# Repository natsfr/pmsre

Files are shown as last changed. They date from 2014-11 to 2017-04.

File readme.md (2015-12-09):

#Powerful Motor System that Rocks Everything

##Presentation
PMSRE is a motor control system originally designed to drive a PCB CNC, a 3D printer and a microscope stage.
This project is based on a STM32F103 + 3x DRV8825 from TI and a Xilinx FPGA Spartan3A 50k or 200k. The main
point of using FPGA is too provide an easy way to extend the board with daughter board and to make real
line and curve machining in CNC.

##Hardware

  PCB is 4 Layers.

##Software

  OpenOCD scripts
  ---------------

  GDB  : openocd -f scripts/openocd/pmsre.cfg -c "gdb_port 4000"
  FLASH: openocd -f scripts/openocd/pmsre.cfg -c "program <elf binary> verify reset"

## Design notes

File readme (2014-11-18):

============================
== Powerfull Motor System ==
== Rocks Everything       ==
============================

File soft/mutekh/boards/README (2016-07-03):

=== OpenOCD ===

cd mutekh/
make BUILD=stm32-f103rg:shell CONF=~/pmsre/soft/mutekh/boards/config
openocd -f interface/ftdi/dp_busblaster.cfg -f target/stm32f1x.cfg -c init -c targets -c halt -c "flash write_image erase pmsre-stm32-f1.out" -c reset run -c shutdown

=== Segger ===

cd mutekh/
make BUILD=stm32-f103rg:shell:binary CONF=~/pmsre/soft/mutekh/boards/config TARGET_EXT=bin
( echo 'device STM32F103RG' ; echo 'loadbin pmsre-stm32-f1.bin 0' ; echo 'r' ; echo 'exit' ) | JLinkExe

==============

Flashing may fail when the mcu is idle, run the
follwing command in the mutekh shell in this case:

dev.timer.wait --timer-dev timer* --msec 10000 --busy-wait

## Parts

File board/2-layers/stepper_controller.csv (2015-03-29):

Reference | Value | Footprint | Datasheet
R201 | 0 | General_SMD:SM0603 | 594-MCT06030Z0000ZP5
R210 | 0 | General_SMD:SM0603 | 594-MCT06030Z0000ZP5
R207 | 22 | General_SMD:SM0603 | 660-RK73H1HTTC22R0F
R208 | 22 | General_SMD:SM0603 | 660-RK73H1HTTC22R0F
R204 | ? | General_SMD:SM0603
R205 | ? | General_SMD:SM0603
R113 | 0.1 | General_SMD:SM1206 | 66-LR1206LF-01-R100F
R114 | 0.1 | General_SMD:SM1206 | 66-LR1206LF-01-R100F
R115 | 0.1 | General_SMD:SM1206 | 66-LR1206LF-01-R100F
R116 | 0.1 | General_SMD:SM1206 | 66-LR1206LF-01-R100F
R117 | 0.1 | General_SMD:SM1206 | 70-LR1206LF-01-R100F
R118 | 0.1 | General_SMD:SM1206 | 70-LR1206LF-01-R100F
C104 | 0.1u | General_SMD:SM0603 | 77-VJ0603V104ZXACBC
C105 | 0.1u | General_SMD:SM0603 | 77-VJ0603V104ZXACBC
C106 | 0.1u | General_SMD:SM0603 | 77-VJ0603V104ZXACBC
C120 | 0.1u | General_SMD:SM0603 | 77-VJ0603V104ZXACBC
C307 | 0.1uF | General_SMD:SM0603 | 77-VJ0603V104ZXACBC
C101 | 0.47u | General_SMD:SM0603 | 77-VJ0603V474ZXJPBC
C102 | 0.47u | General_SMD:SM0603 | 77-VJ0603V474ZXJPBC
C103 | 0.47u | General_SMD:SM0603 | 77-VJ0603V474ZXJPBC
R206 | 1.5k | General_SMD:SM0603 | 71-CRCW0603-1.5K-E3
R304 | 100k | General_SMD:SM0603 | 71-CRCW0603-100K-E3
C122 | 100n | General_SMD:SM0603 | 77-VJ0603V104ZXACBC
C123 | 100n | General_SMD:SM0603 | 77-VJ0603V104ZXACBC
C124 | 100n | General_SMD:SM0603 | 77-VJ0603V104ZXACBC
C403 | 100n | General_SMD:SM0603 | 77-VJ0603V104ZXACBC
C404 | 100n | General_SMD:SM0603 | 77-VJ0603V104ZXACBC
C405 | 100n | General_SMD:SM0603 | 77-VJ0603V104ZXACBC
C409 | 100n | General_SMD:SM0603 | 77-VJ0603V104ZXACBC
C411 | 100n | General_SMD:SM0603 | 77-VJ0603V104ZXACBC
C413 | 100n | General_SMD:SM0603 | 77-VJ0603V104ZXACBC
C415 | 100n | General_SMD:SM0603 | 77-VJ0603V104ZXACBC
R202 | 10k | General_SMD:SM0603 | 71-CRCW0603-10K-E3
R209 | 10k | General_SMD:SM0603 | 71-CRCW0603-10K-E3
R301 | 10k | General_SMD:SM0603 | 71-CRCW0603-10K-E3
R307 | 10k | General_SMD:SM0603 | 71-CRCW0603-10K-E3
C107 | 10n | General_SMD:SM0603 | 77-VJ0603Y103KXAAC
C108 | 10n | General_SMD:SM0603 | 77-VJ0603Y103KXAAC
C109 | 10n | General_SMD:SM0603 | 77-VJ0603Y103KXAAC
C121 | 10n | General_SMD:SM0603 | 77-VJ0603Y103KXAAC
C406 | 10n | General_SMD:SM0603 | 77-VJ0603Y103KXAAC
C407 | 10n | General_SMD:SM0603 | 77-VJ0603Y103KXAAC
C308 | 10nF | General_SMD:SM0603 | 77-VJ0603Y103KXAAC
C311 | 10uF | General_SMD:SM0805 | 77-VJ0805G106KXQTBC
C313 | 10uF | General_SMD:SM0805 | 77-VJ0805G106KXQTBC
C314 | 10uF | General_SMD:SM0805 | 77-VJ0805G106KXQTBC
C315 | 10uF | General_SMD:SM0805 | 77-VJ0805G106KXQTBC
C304 | 10uF | General_SMD:SM1210 | 963-TMK325F106ZH-T
C305 | 10uF | General_SMD:SM1210 | 963-TMK325F106ZH-T
L302 | 10uH | General_SMD:IND_7x7x4.5 | 810-SLF755T100M2R5PF
P301 | 12V_Conn | Connectors_508mm:MOL_CONN_2_VH | #####################
R107 | 1M | General_SMD:SM0603 | 71-CRCW0603-1.0M-E3
R108 | 1M | General_SMD:SM0603 | 71-CRCW0603-1.0M-E3
R109 | 1M | General_SMD:SM0603 | 71-CRCW0603-1.0M-E3
C119 | 1u | General_SMD:SM0603 | 963-TMK107BJ105KA-T
C401 | 1u | General_SMD:SM0603 | 963-TMK107BJ105KA-T
C402 | 1u | General_SMD:SM0603 | 963-TMK107BJ105KA-T
C408 | 1u | General_SMD:SM0603 | 963-TMK107BJ105KA-T
C410 | 1u | General_SMD:SM0603 | 963-TMK107BJ105KA-T
C412 | 1u | General_SMD:SM0603 | 963-TMK107BJ105KA-T
C414 | 1u | General_SMD:SM0603 | 963-TMK107BJ105KA-T
L301 | 1u | General_SMD:SM1210L | 81-LQM32PN1R0MG0L
C201 | 1uF | General_SMD:SM0603 | 963-TMK107BJ105KA-T
C202 | 1uF | General_SMD:SM0603 | 963-TMK107BJ105KA-T
C203 | 1uF | General_SMD:SM0603 | 963-TMK107BJ105KA-T
C204 | 1uF | General_SMD:SM0603 | 963-TMK107BJ105KA-T
C205 | 1uF | General_SMD:SM0603 | 963-TMK107BJ105KA-T
C206 | 1uF | General_SMD:SM0603 | 963-TMK107BJ105KA-T
C207 | 1uF | General_SMD:SM0603 | 963-TMK107BJ105KA-T
C312 | 1uF | General_SMD:SM0805 | 77-VJ0805V105ZXJCBC
C309 | 1uF | General_SMD:SM1210 | 603-CC121KKX7R8BB105
R302 | 200k | General_SMD:SM0603 | 71-CRCW0603-200K-E3
R303 | 200k | General_SMD:SM0603 | 71-CRCW0603-200K-E3
R308 | 30.9k | General_SMD:SM0603 | 71-CRCW0603-30.9K-E3
R305 | 4.42k | General_SMD:SM0603 | 71-CRCW0603-4.42K-E3
C306 | 4.7nF | General_SMD:SM0603 | 963-TMK107B7474KA-TR
C110 | 4.7u | General_SMD:SM0805 | 570-08053D475K
C111 | 4.7u | General_SMD:SM0805 | 571-08053D475K
C112 | 4.7u | General_SMD:SM0805 | 572-08053D475K
C113 | 4.7u | General_SMD:SM0805 | 573-08053D475K
C114 | 4.7u | General_SMD:SM0805 | 574-08053D475K
C115 | 4.7u | General_SMD:SM0805 | 575-08053D475K
C116 | 4.7u | General_SMD:SM0805 | 576-08053D475K
C117 | 4.7u | General_SMD:SM0805 | 577-08053D475K
C118 | 4.7u | General_SMD:SM0805 | 578-08053D475K
C301 | 4.7u | General_SMD:SM0805 | 579-08053D475K
C302 | 4.7u | General_SMD:SM0805 | 580-08053D475K
C303 | 4.7u | General_SMD:SM0805 | 581-08053D475K
C310 | 4.7uF | General_SMD:SM1210 | 963-GMK325BJ475MN-T
R306 | 47k | General_SMD:SM0603 | 594-MCT06030C4702FP5
D202 | BUSY_ORANGE | General_SMD:LED-0805 | 755-SML-M13DTT86
P202 | CONN_2 | Connectors_254mm:pin_array_2x1 | #####################
P201 | CONN_2X2 | Connectors_254mm:pin_array_2x2 | #####################
P103 | CONN_4 | Connectors_508mm:MOL_CONN_4_VH | #####################
P105 | CONN_4 | Connectors_508mm:MOL_CONN_4_VH | #####################
P107 | CONN_4 | Connectors_508mm:MOL_CONN_4_VH | #####################
P108 | CONN_4X2 | Connectors_254mm:pin_array_4x2 | #####################
P106 | CONN_6X2 | Connectors_254mm:pin_array_6x2 | #####################
P104 | CONN_8X2 | Connectors_254mm:pin_array_8x2 | #####################
C208 | CSMALL | General_SMD:SM0603 | 81-GCM1885C2A160JA6D
C209 | CSMALL | General_SMD:SM0603 | 81-GCM1885C2A160JA6D
U101 | DRV8825 | SSOP:HTSSOP28_PowerPad | #####################
U102 | DRV8825 | SSOP:HTSSOP28_PowerPad | #####################
U103 | DRV8825 | SSOP:HTSSOP28_PowerPad | #####################
P101 | JTAG | Connectors_254mm:pin_array_6x1 | #####################
P102 | JTAG | Connectors_254mm:pin_array_6x1 | #####################
U104 | MAX5713/4/5-TSSOP14 | SSOP:SSOP14 | #####################
U301 | MP2128-SOT23 | General_SMD:SOT23-5 | #####################
U302 | MP2303_SOIC8E | SOIC:SO8_WITH_EP | #####################
R101 | NE | General_SMD:SM0603
R102 | NE | General_SMD:SM0603
R103 | NE | General_SMD:SM0603
R104 | NE | General_SMD:SM0603
R105 | NE | General_SMD:SM0603
R106 | NE | General_SMD:SM0603
R403 | NE | General_SMD:SM0603
D203 | POWER_GREEN | General_SMD:LED-0805 | 720-LGR971-KN-1
R401 | R | General_SMD:SM0603
R402 | R | General_SMD:SM0603
R404 | R | General_SMD:SM0603
U201 | STM32F103RG_LQFP64 | QFP:LQFP_64 | #####################
X201 | TXC_50X32_AB | Xtal_SMD:XTAL_5.0x3.2mm | #####################
J201 | USB_OTG | Connectors_USB:Molex_54819-0572 | 538-54819-0572
U401 | XC3S200A | QFP:TQFP_100 | #####################

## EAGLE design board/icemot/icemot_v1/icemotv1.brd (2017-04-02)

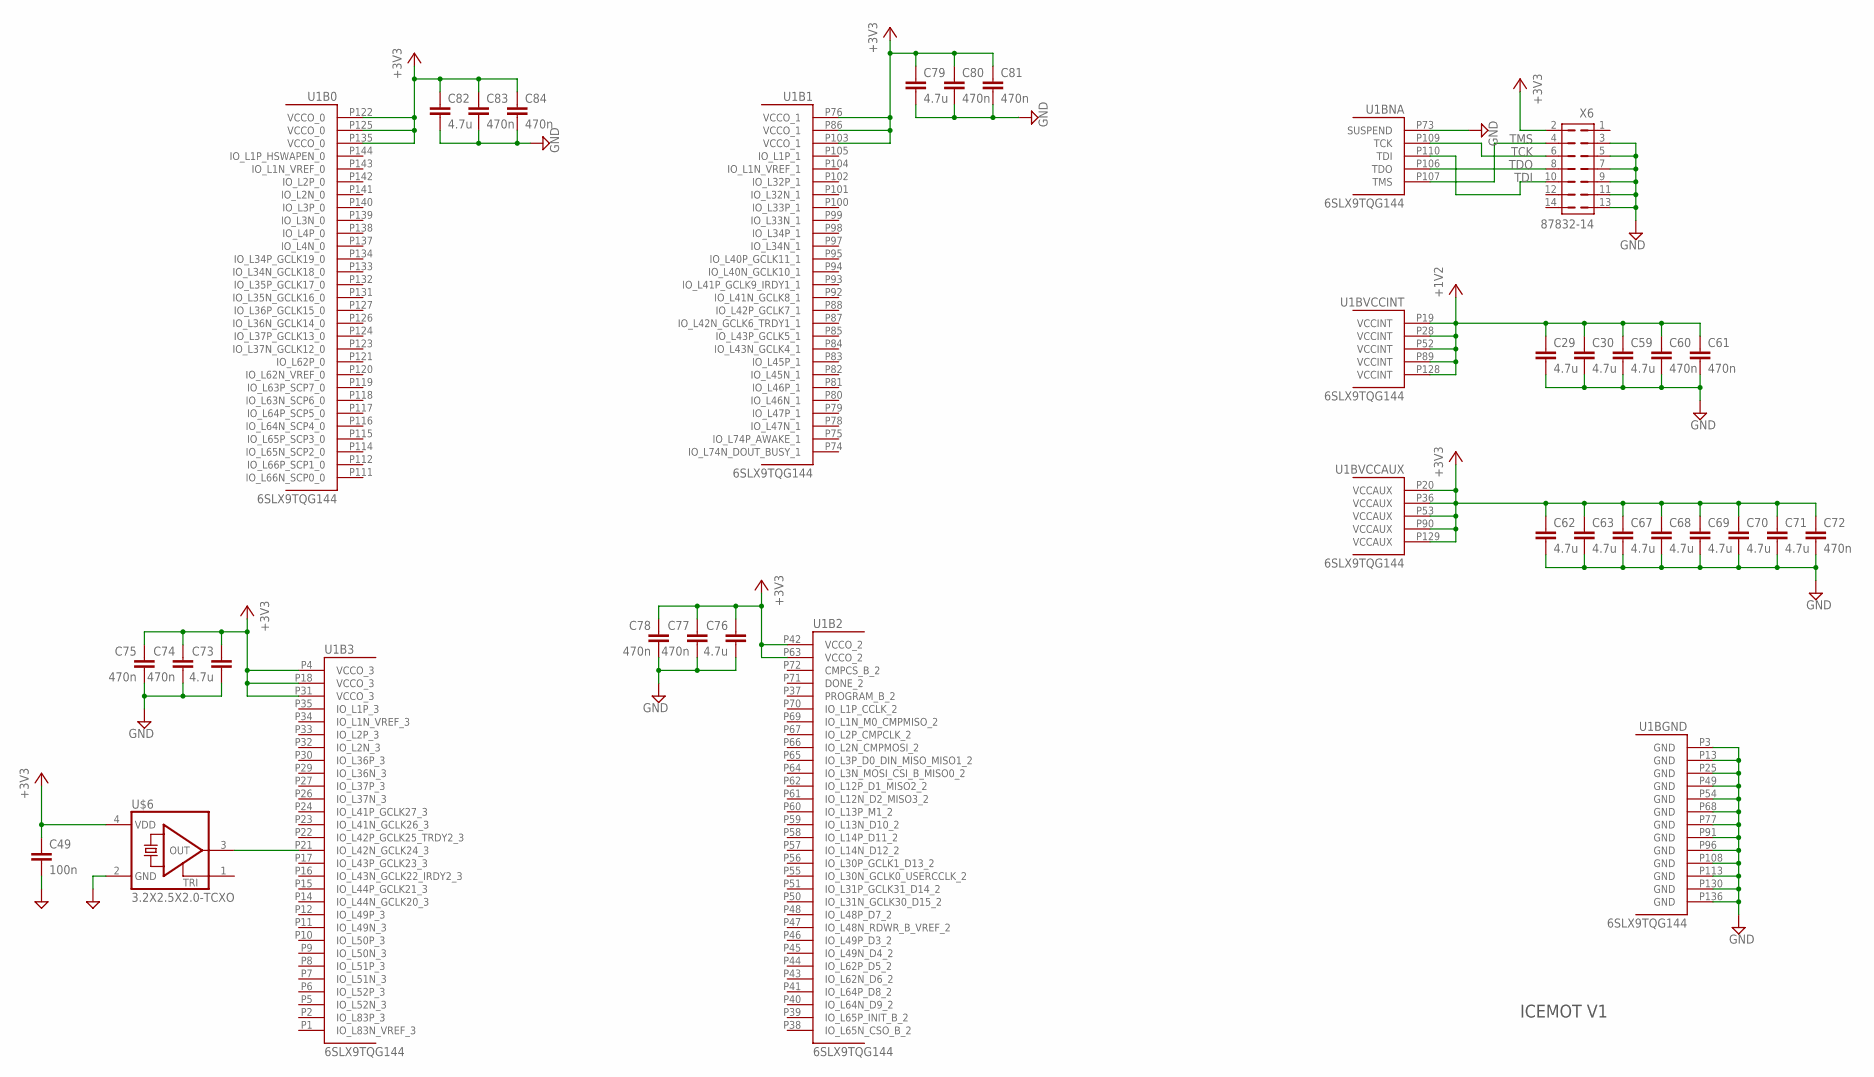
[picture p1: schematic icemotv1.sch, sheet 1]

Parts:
C29, C30, C59, C62, C63, C67, C68, C69, C70, C71, C73, C76, C79, C82: 4.7u; C0603
C49: 100n; R0603
C60, C61, C72, C74, C75, C77, C78, C80, C81, C83, C84: 470n; C0603
U1: 6SLX9TQG144; TQ144
U$6: 3.2X2.5X2.0-TCXO
X6: 87832-14

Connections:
+1V2: C29.1, C30.1, C59.1, C60.1, C61.1
+3V3: C49.1, C62.1, C63.1, C67.1, C68.1, C69.1, C70.1, C71.1, C72.1, C73.1, C74.1, C75.1, C76.1, C77.1, C78.1, C79.1, C80.1, C81.1, C82.1, C83.1, C84.1, U1.P20 (VCCAUX), U1.P36 (VCCAUX), U1.P53 (VCCAUX), U1.P90 (VCCAUX), U1.P129 (VCCAUX), U$6.4 (VDD), X6.2; also elsewhere on the board
GND: C29.2, C30.2, C49.2, C59.2, C60.2, C61.2, C62.2, C63.2, C67.2, C68.2, C69.2, C70.2, C71.2, C72.2, C73.2, C74.2, C75.2, C76.2, C77.2, C78.2, C79.2, C80.2, C81.2, C82.2, C83.2, C84.2, U1.P3 (GND), U1.P13 (GND), U1.P25 (GND), U1.P49 (GND), U1.P54 (GND), U1.P68 (GND), U1.P73 (SUSPEND), U1.P77 (GND), U1.P91 (GND), U1.P96 (GND), U1.P108 (GND), U1.P113 (GND), U1.P130 (GND), U1.P136 (GND), U$6.2 (GND), X6.3, X6.5, X6.7, X6.9, X6.11, X6.13; also elsewhere on the board
unnamed: U1.P21 (IO_L42N_GCLK24_3), U$6.3 (OUT)
TCK: U1.P109 (TCK), X6.6
TDI: U1.P110 (TDI), X6.10
TDO: U1.P106 (TDO), X6.8
TMS: U1.P107 (TMS), X6.4

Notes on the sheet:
ICEMOT V1

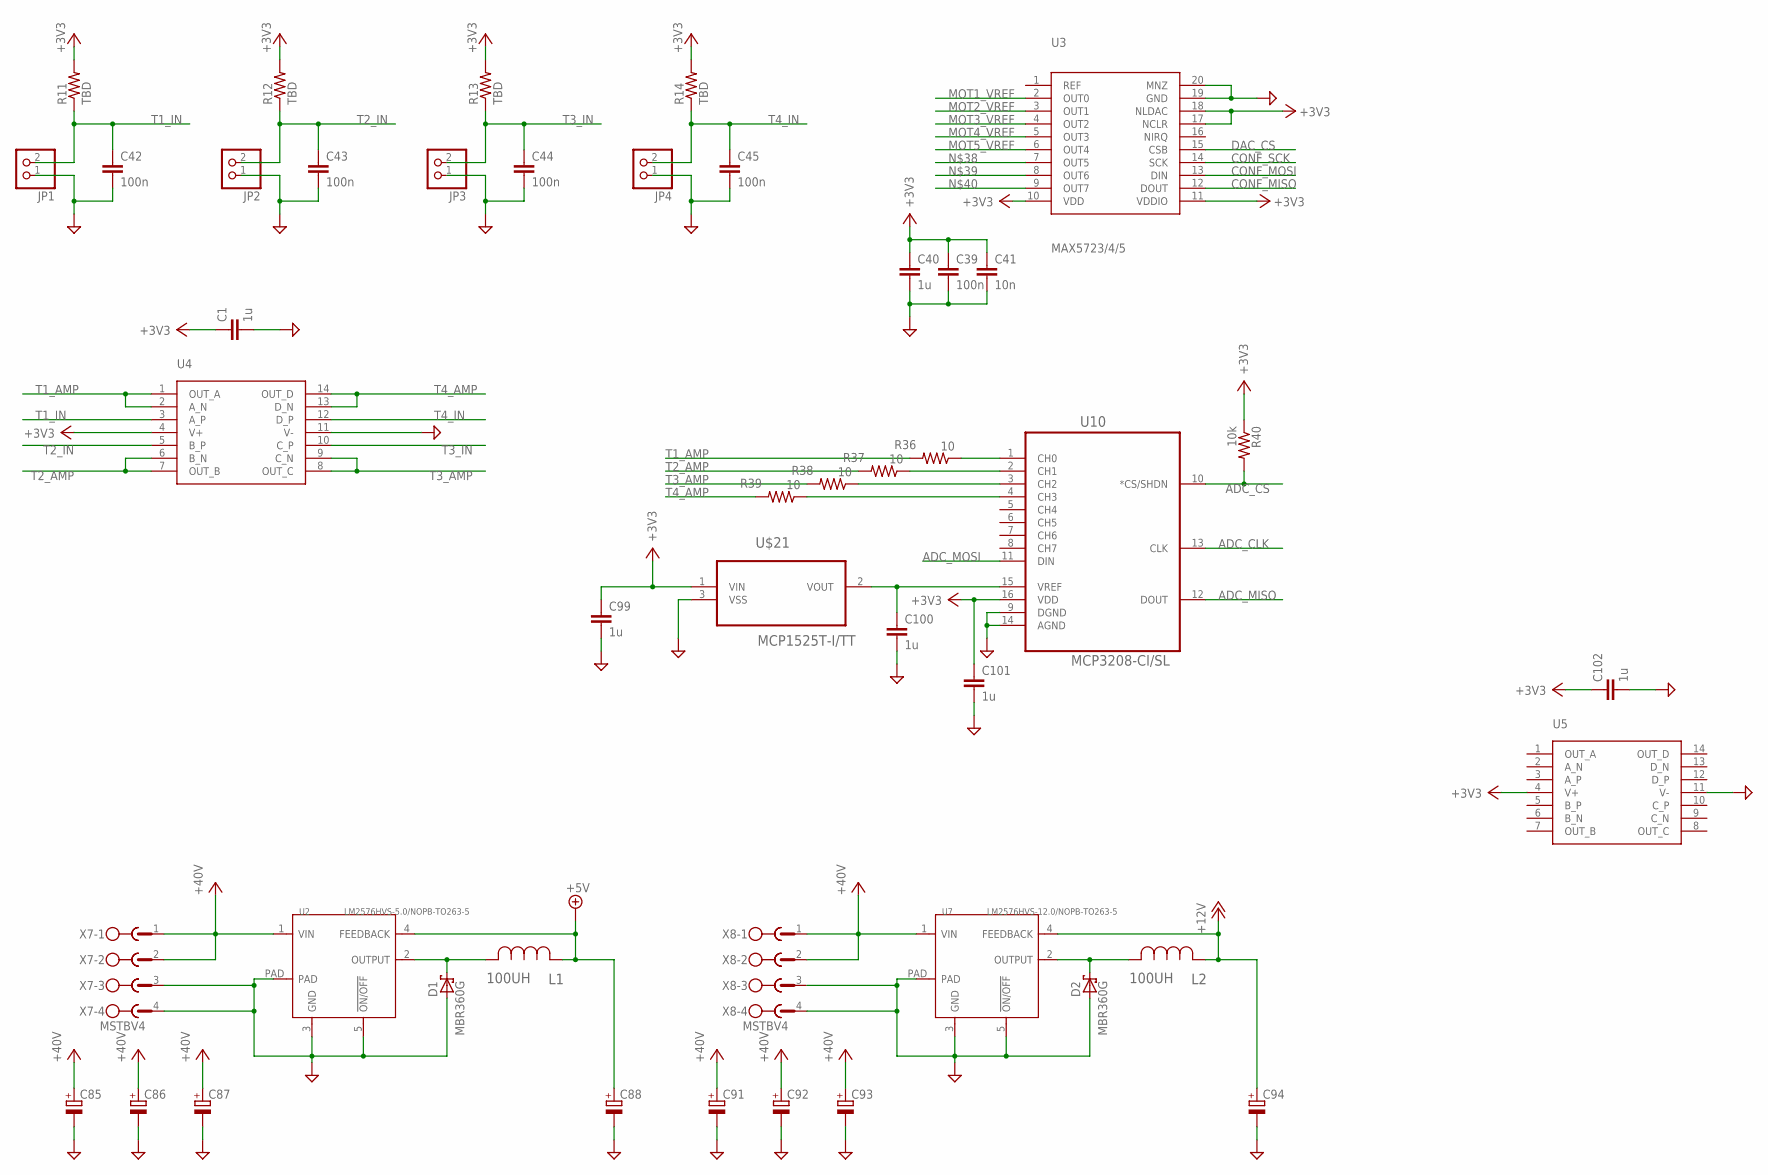
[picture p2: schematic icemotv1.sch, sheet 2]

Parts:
C1, C40, C99, C100, C101, C102: 1u; R0603
C39, C42, C43, C44, C45: 100n; R0603
C41: 10n; R0603
C85, C86, C87, C88, C91, C92, C93, C94: CPOL-EUE5-10.5; E5-10,5
D1, D2: MBR360G; DO201T15
JP1, JP2, JP3, JP4: PINHD-1X2; 1X02
L1, L2: 100UH; IND_ELC18B
R11, R12, R13, R14: TBD; R0603
R36, R37, R38, R39: 10; R0603
R40: 10k; R0603
U2: LM2576HVS-5.0/NOPB-TO263-5; TO-263-5
U3: MAX5723/4/5; TSSOP20-0.65-6.5X4.4MM
U4, U5: TLV4379; TSSOP14-0.65-5X4.4MM
U7: LM2576HVS-12.0/NOPB-TO263-5; TO-263-5
U10: MCP3208-CI/SL; SOIC127P600X175-16N
U$21: MCP1525T-I/TT; SOT96P237X112-3N
X7, X8: MSTBV4

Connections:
+3V3: C1.1, C39.1, C40.1, C41.1, C99.1, C101.1, C102.1, R11.2, R12.2, R13.2, R14.2, R40.1, U3.10 (VDD), U3.11 (VDDIO), U3.17 (NCLR), U3.18 (NLDAC), U4.4 (V+), U10.16 (VDD), U$21.1 (VIN); also elsewhere on the board
+5V: C88.+, L1.1, U2.4 (FEEDBACK)
+12V: C94.+, L2.1, U7.4 (FEEDBACK); also elsewhere on the board
+40V: C85.+, C86.+, C87.+, C91.+, C92.+, C93.+, U2.1 (VIN), U7.1 (VIN), X7.1, X7.2, X8.1, X8.2; also elsewhere on the board
ADC_CLK: U10.13 (CLK)
ADC_CS: R40.2, U10.10 (*CS/SHDN)
ADC_MISO: U10.12 (DOUT)
ADC_MOSI: U10.11 (DIN)
CONF_MISO: U3.12 (DOUT)
CONF_MOSI: U3.13 (DIN)
CONF_SCK: U3.14 (SCK)
DAC_CS: U3.15 (CSB)
GND: C1.2, C39.2, C40.2, C41.2, C42.2, C43.2, C44.2, C45.2, C85.-, C86.-, C87.-, C88.-, C91.-, C92.-, C93.-, C94.-, C99.2, C100.2, C101.2, C102.2, D1.A, D2.A, JP1.1, JP2.1, JP3.1, JP4.1, U2.3 (GND), U2.5 (!ON/OFF), U2.PAD, U3.19 (GND), U3.20 (MNZ), U4.11 (V-), U7.3 (GND), U7.5 (!ON/OFF), U7.PAD, U10.9 (DGND), U10.14 (AGND), U$21.3 (VSS), X7.3, X7.4, X8.3, X8.4; also elsewhere on the board
MOT1_VREF: U3.2 (OUT0); also elsewhere on the board
MOT2_VREF: U3.3 (OUT1); also elsewhere on the board
MOT3_VREF: U3.4 (OUT2); also elsewhere on the board
MOT4_VREF: U3.5 (OUT3); also elsewhere on the board
MOT5_VREF: U3.6 (OUT4); also elsewhere on the board
unnamed: D1.C, L1.2, U2.2 (OUTPUT)
unnamed: D2.C, L2.2, U7.2 (OUTPUT)
unnamed: C100.1, U10.15 (VREF), U$21.2 (VOUT)
unnamed: R36.1, U10.1 (CH0)
unnamed: R37.1, U10.2 (CH1)
unnamed: R38.1, U10.3 (CH2)
unnamed: R39.1, U10.4 (CH3)
T1_AMP: R36.2, U4.1 (OUT_A), U4.2 (A_N)
T1_IN: C42.1, JP1.2, R11.1, U4.3 (A_P)
T2_AMP: R37.2, U4.6 (B_N), U4.7 (OUT_B)
T2_IN: C43.1, JP2.2, R12.1, U4.5 (B_P)
T3_AMP: R38.2, U4.8 (OUT_C), U4.9 (C_N)
T3_IN: C44.1, JP3.2, R13.1, U4.10 (C_P)
T4_AMP: R39.2, U4.13 (D_N), U4.14 (OUT_D)
T4_IN: C45.1, JP4.2, R14.1, U4.12 (D_P)
V+: U5.4 (V+)
V-: U5.11 (V-)

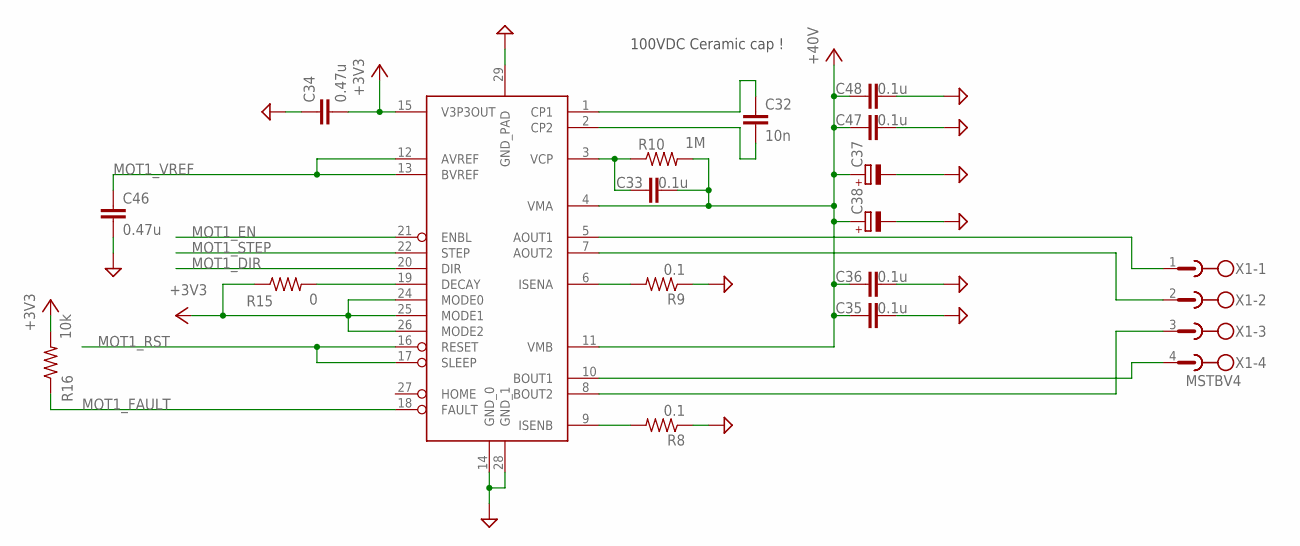
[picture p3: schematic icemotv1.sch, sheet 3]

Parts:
C32: 10n; R0603
C33, C35, C36, C47, C48: 0.1u; R0603
C34, C46: 0.47u; R0603
C37, C38: CPOL-EUE5-5; E5-5
R8, R9: 0.1; R1206
R10: 1M; R0603
R15: 0; R0603
R16: 10k; R0603
U$4: DRV8825PWP; TSSOP-28
X1: MSTBV4

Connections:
+3V3: C34.2, R15.1, R16.2, U$4.15 (V3P3OUT), U$4.24 (MODE0), U$4.25 (MODE1), U$4.26 (MODE2); also elsewhere on the board
+40V: C33.2, C35.1, C36.1, C37.+, C38.+, C47.1, C48.1, R10.2, U$4.4 (VMA), U$4.11 (VMB); also elsewhere on the board
GND: C34.1, C35.2, C36.2, C37.-, C38.-, C46.2, C47.2, C48.2, R8.1, R9.1, U$4.14 (GND_0), U$4.28 (GND_1), U$4.29 (GND_PAD); also elsewhere on the board
MOT1_DIR: U$4.20 (DIR)
MOT1_EN: U$4.21 (ENBL)
MOT1_FAULT: R16.1, U$4.18 (FAULT)
MOT1_RST: U$4.16 (RESET), U$4.17 (SLEEP)
MOT1_STEP: U$4.22 (STEP)
MOT1_VREF: C46.1, U$4.12 (AVREF), U$4.13 (BVREF); also elsewhere on the board
unnamed: R9.2, U$4.6 (ISENA)
unnamed: R8.2, U$4.9 (ISENB)
unnamed: C32.1, U$4.1 (CP1)
unnamed: C32.2, U$4.2 (CP2)
unnamed: C33.1, R10.1, U$4.3 (VCP)
unnamed: R15.2, U$4.19 (DECAY)
unnamed: U$4.5 (AOUT1), X1.1
unnamed: U$4.7 (AOUT2), X1.2
unnamed: U$4.8 (BOUT2), X1.3
unnamed: U$4.10 (BOUT1), X1.4

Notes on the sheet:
100VDC Ceramic cap !

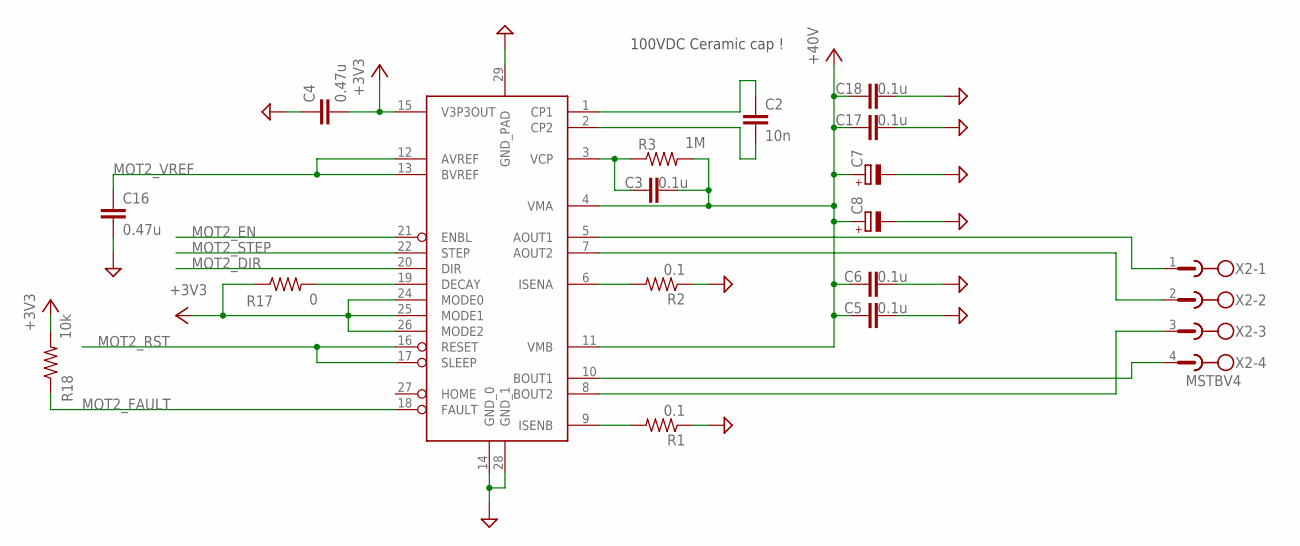
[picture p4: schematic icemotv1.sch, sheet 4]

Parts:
C2: 10n; R0603
C3, C5, C6, C17, C18: 0.1u; R0603
C4, C16: 0.47u; R0603
C7, C8: CPOL-EUE5-5; E5-5
R1, R2: 0.1; R1206
R3: 1M; R0603
R17: 0; R0603
R18: 10k; R0603
U$1: DRV8825PWP; TSSOP-28
X2: MSTBV4

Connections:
+3V3: C4.2, R17.1, R18.2, U$1.15 (V3P3OUT), U$1.24 (MODE0), U$1.25 (MODE1), U$1.26 (MODE2); also elsewhere on the board
+40V: C3.2, C5.1, C6.1, C7.+, C8.+, C17.1, C18.1, R3.2, U$1.4 (VMA), U$1.11 (VMB); also elsewhere on the board
GND: C4.1, C5.2, C6.2, C7.-, C8.-, C16.2, C17.2, C18.2, R1.1, R2.1, U$1.14 (GND_0), U$1.28 (GND_1), U$1.29 (GND_PAD); also elsewhere on the board
MOT2_DIR: U$1.20 (DIR)
MOT2_EN: U$1.21 (ENBL)
MOT2_FAULT: R18.1, U$1.18 (FAULT)
MOT2_RST: U$1.16 (RESET), U$1.17 (SLEEP)
MOT2_STEP: U$1.22 (STEP)
MOT2_VREF: C16.1, U$1.12 (AVREF), U$1.13 (BVREF); also elsewhere on the board
unnamed: R2.2, U$1.6 (ISENA)
unnamed: R1.2, U$1.9 (ISENB)
unnamed: C2.1, U$1.1 (CP1)
unnamed: C2.2, U$1.2 (CP2)
unnamed: C3.1, R3.1, U$1.3 (VCP)
unnamed: U$1.5 (AOUT1), X2.1
unnamed: U$1.7 (AOUT2), X2.2
unnamed: U$1.8 (BOUT2), X2.3
unnamed: U$1.10 (BOUT1), X2.4
unnamed: R17.2, U$1.19 (DECAY)

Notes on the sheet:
100VDC Ceramic cap !

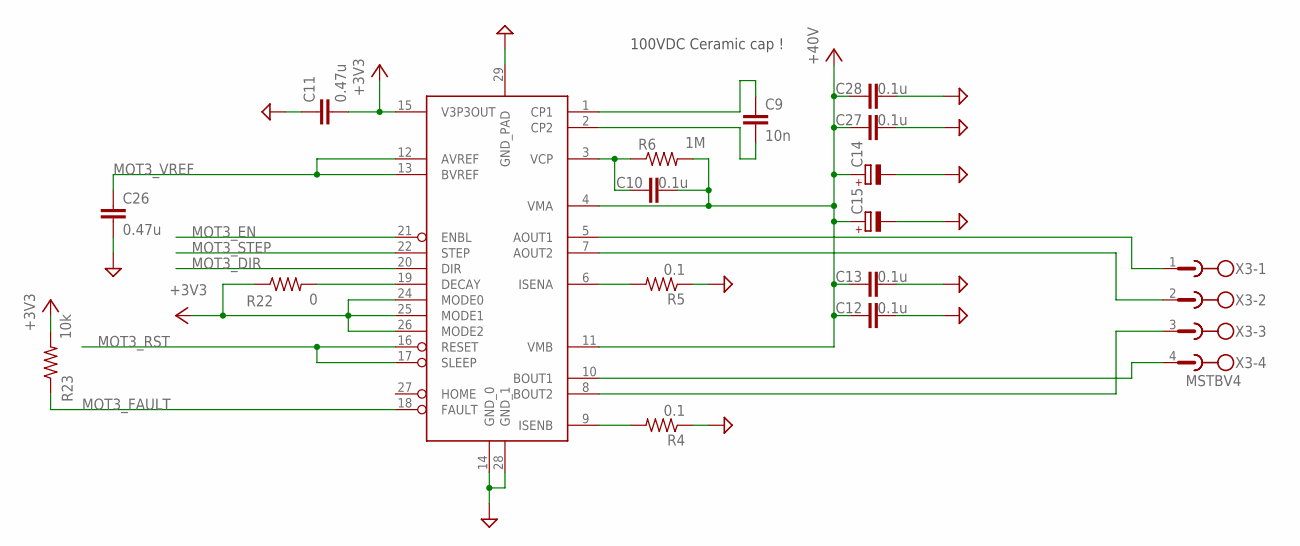
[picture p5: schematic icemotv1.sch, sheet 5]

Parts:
C9: 10n; R0603
C10, C12, C13, C27, C28: 0.1u; R0603
C11, C26: 0.47u; R0603
C14, C15: CPOL-EUE5-5; E5-5
R4, R5: 0.1; R1206
R6: 1M; R0603
R22: 0; R0603
R23: 10k; R0603
U$3: DRV8825PWP; TSSOP-28
X3: MSTBV4

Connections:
+3V3: C11.2, R22.1, R23.2, U$3.15 (V3P3OUT), U$3.24 (MODE0), U$3.25 (MODE1), U$3.26 (MODE2); also elsewhere on the board
+40V: C10.2, C12.1, C13.1, C14.+, C15.+, C27.1, C28.1, R6.2, U$3.4 (VMA), U$3.11 (VMB); also elsewhere on the board
GND: C11.1, C12.2, C13.2, C14.-, C15.-, C26.2, C27.2, C28.2, R4.1, R5.1, U$3.14 (GND_0), U$3.28 (GND_1), U$3.29 (GND_PAD); also elsewhere on the board
MOT3_DIR: U$3.20 (DIR)
MOT3_EN: U$3.21 (ENBL)
MOT3_FAULT: R23.1, U$3.18 (FAULT)
MOT3_RST: U$3.16 (RESET), U$3.17 (SLEEP)
MOT3_STEP: U$3.22 (STEP)
MOT3_VREF: C26.1, U$3.12 (AVREF), U$3.13 (BVREF); also elsewhere on the board
unnamed: R5.2, U$3.6 (ISENA)
unnamed: R4.2, U$3.9 (ISENB)
unnamed: C9.1, U$3.1 (CP1)
unnamed: C9.2, U$3.2 (CP2)
unnamed: C10.1, R6.1, U$3.3 (VCP)
unnamed: U$3.5 (AOUT1), X3.1
unnamed: U$3.7 (AOUT2), X3.2
unnamed: U$3.8 (BOUT2), X3.3
unnamed: U$3.10 (BOUT1), X3.4
unnamed: R22.2, U$3.19 (DECAY)

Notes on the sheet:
100VDC Ceramic cap !

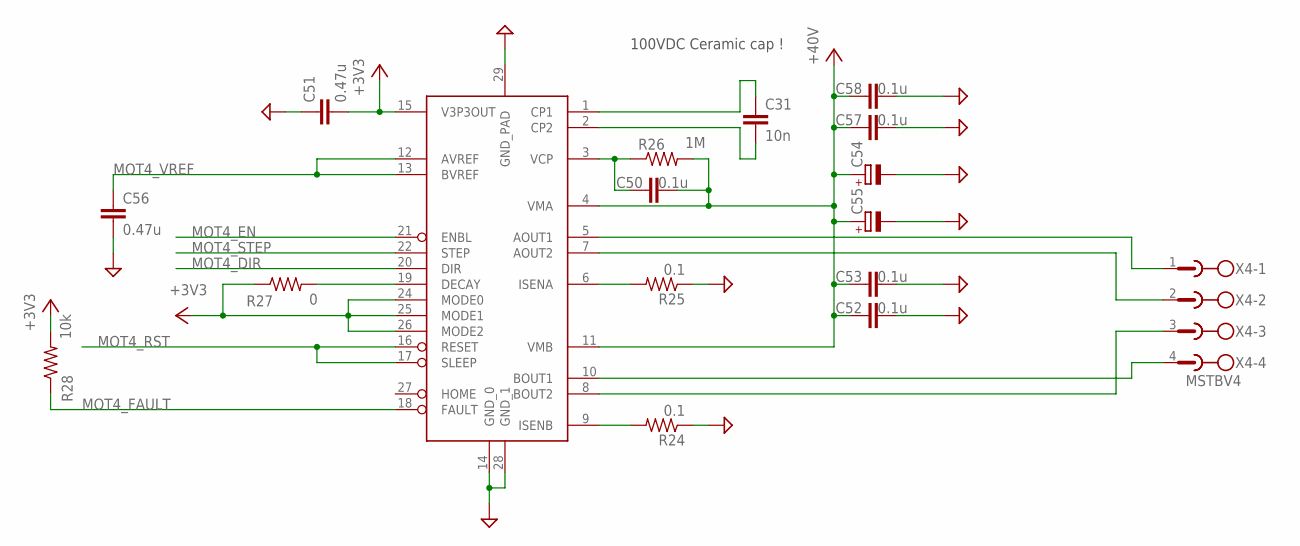
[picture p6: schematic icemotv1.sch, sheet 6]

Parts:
C31: 10n; R0603
C50, C52, C53, C57, C58: 0.1u; R0603
C51, C56: 0.47u; R0603
C54, C55: CPOL-EUE5-5; E5-5
R24, R25: 0.1; R1206
R26: 1M; R0603
R27: 0; R0603
R28: 10k; R0603
U$9: DRV8825PWP; TSSOP-28
X4: MSTBV4

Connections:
+3V3: C51.2, R27.1, R28.2, U$9.15 (V3P3OUT), U$9.24 (MODE0), U$9.25 (MODE1), U$9.26 (MODE2); also elsewhere on the board
+40V: C50.2, C52.1, C53.1, C54.+, C55.+, C57.1, C58.1, R26.2, U$9.4 (VMA), U$9.11 (VMB); also elsewhere on the board
GND: C51.1, C52.2, C53.2, C54.-, C55.-, C56.2, C57.2, C58.2, R24.1, R25.1, U$9.14 (GND_0), U$9.28 (GND_1), U$9.29 (GND_PAD); also elsewhere on the board
MOT4_DIR: U$9.20 (DIR)
MOT4_EN: U$9.21 (ENBL)
MOT4_FAULT: R28.1, U$9.18 (FAULT)
MOT4_RST: U$9.16 (RESET), U$9.17 (SLEEP)
MOT4_STEP: U$9.22 (STEP)
MOT4_VREF: C56.1, U$9.12 (AVREF), U$9.13 (BVREF); also elsewhere on the board
unnamed: R25.2, U$9.6 (ISENA)
unnamed: R24.2, U$9.9 (ISENB)
unnamed: C31.1, U$9.1 (CP1)
unnamed: C31.2, U$9.2 (CP2)
unnamed: C50.1, R26.1, U$9.3 (VCP)
unnamed: U$9.5 (AOUT1), X4.1
unnamed: U$9.7 (AOUT2), X4.2
unnamed: U$9.8 (BOUT2), X4.3
unnamed: U$9.10 (BOUT1), X4.4
unnamed: R27.2, U$9.19 (DECAY)

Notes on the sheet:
100VDC Ceramic cap !

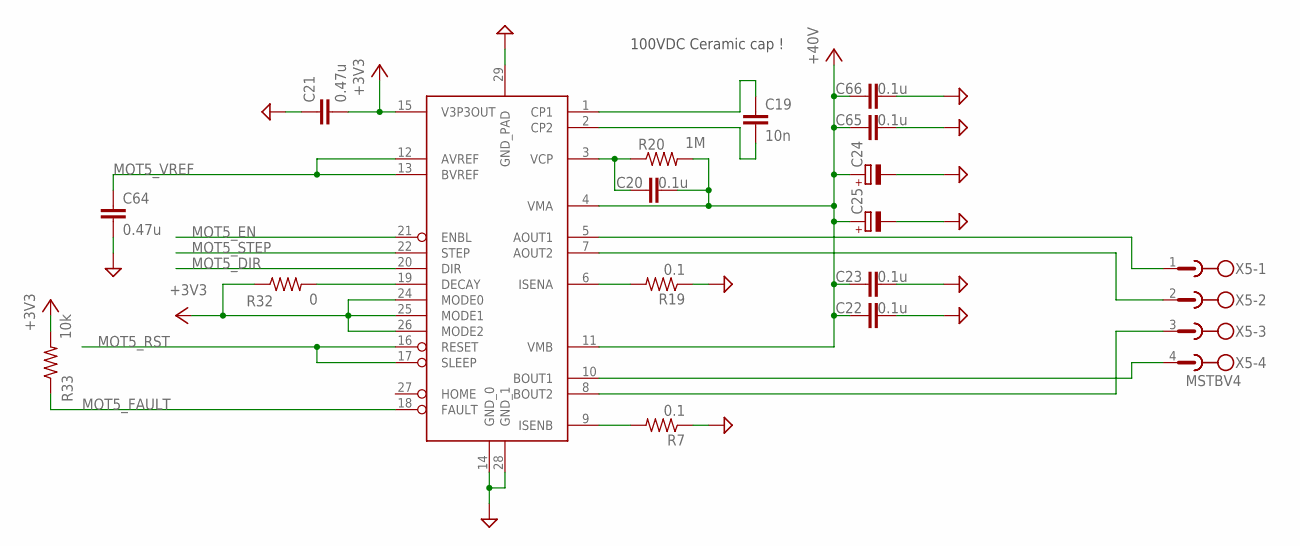
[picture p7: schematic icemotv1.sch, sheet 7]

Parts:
C19: 10n; R0603
C20, C22, C23, C65, C66: 0.1u; R0603
C21, C64: 0.47u; R0603
C24, C25: CPOL-EUE5-5; E5-5
R7, R19: 0.1; R1206
R20: 1M; R0603
R32: 0; R0603
R33: 10k; R0603
U$8: DRV8825PWP; TSSOP-28
X5: MSTBV4

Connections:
+3V3: C21.2, R32.1, R33.2, U$8.15 (V3P3OUT), U$8.24 (MODE0), U$8.25 (MODE1), U$8.26 (MODE2); also elsewhere on the board
+40V: C20.2, C22.1, C23.1, C24.+, C25.+, C65.1, C66.1, R20.2, U$8.4 (VMA), U$8.11 (VMB); also elsewhere on the board
GND: C21.1, C22.2, C23.2, C24.-, C25.-, C64.2, C65.2, C66.2, R7.1, R19.1, U$8.14 (GND_0), U$8.28 (GND_1), U$8.29 (GND_PAD); also elsewhere on the board
MOT5_DIR: U$8.20 (DIR)
MOT5_EN: U$8.21 (ENBL)
MOT5_FAULT: R33.1, U$8.18 (FAULT)
MOT5_RST: U$8.16 (RESET), U$8.17 (SLEEP)
MOT5_STEP: U$8.22 (STEP)
MOT5_VREF: C64.1, U$8.12 (AVREF), U$8.13 (BVREF); also elsewhere on the board
unnamed: R19.2, U$8.6 (ISENA)
unnamed: R7.2, U$8.9 (ISENB)
unnamed: C19.1, U$8.1 (CP1)
unnamed: C19.2, U$8.2 (CP2)
unnamed: C20.1, R20.1, U$8.3 (VCP)
unnamed: U$8.5 (AOUT1), X5.1
unnamed: U$8.7 (AOUT2), X5.2
unnamed: U$8.8 (BOUT2), X5.3
unnamed: U$8.10 (BOUT1), X5.4
unnamed: R32.2, U$8.19 (DECAY)

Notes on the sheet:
100VDC Ceramic cap !

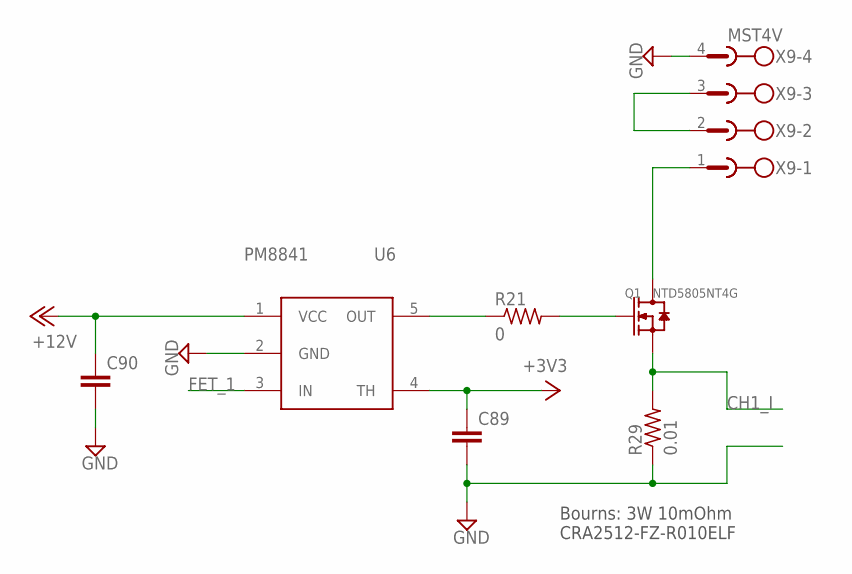
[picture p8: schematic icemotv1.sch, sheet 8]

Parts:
C89, C90: C-EUC0603; C0603
Q1: NTD5805NT4G; DPAK
R21: 0; R1206
R29: 0.01; R2512
U6: PM8841; SOT23-5
X9: MST4V; MSTBV4

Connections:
+3V3: C89.1, U6.4 (TH); also elsewhere on the board
+12V: C90.1, U6.1 (VCC); also elsewhere on the board
CH1_I: Q1.3 (S), R29.2
FET_1: U6.3 (IN)
GND: C89.2, C90.2, R29.1, U6.2 (GND), X9.4; also elsewhere on the board
unnamed: Q1.2 (D), X9.1
unnamed: R21.1, U6.5 (OUT)
unnamed: Q1.1 (G), R21.2
unnamed: X9.2, X9.3

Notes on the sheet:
Bourns: 3W 10mOhm CRA2512-FZ-R010ELF

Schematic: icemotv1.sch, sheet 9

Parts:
C95, C96: C-EUC0603; C0603
Q2: NTD5805NT4G; DPAK
R30: 0; R1206
R31: 0.01; R2512
U8: PM8841; SOT23-5
X10: MST4V; MSTBV4

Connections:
+3V3: C95.1, U8.4 (TH); also elsewhere on the board
+12V: C96.1, U8.1 (VCC); also elsewhere on the board
CH2_I: Q2.3 (S), R31.2
FET_2: U8.3 (IN)
GND: C95.2, C96.2, R31.1, U8.2 (GND), X10.4; also elsewhere on the board
unnamed: R30.1, U8.5 (OUT)
unnamed: Q2.1 (G), R30.2
unnamed: Q2.2 (D), X10.1
unnamed: X10.2, X10.3

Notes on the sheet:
Bourns: 3W 10mOhm CRA2512-FZ-R010ELF

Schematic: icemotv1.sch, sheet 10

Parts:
C97, C98: C-EUC0603; C0603
Q3: NTD5805NT4G; DPAK
R34: 0; R1206
R35: 0.01; R2512
U9: PM8841; SOT23-5
X11: MST4V; MSTBV4

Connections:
+3V3: C97.1, U9.4 (TH); also elsewhere on the board
+12V: C98.1, U9.1 (VCC); also elsewhere on the board
CH3_I: Q3.3 (S), R35.2
FET_3: U9.3 (IN)
GND: C97.2, C98.2, R35.1, U9.2 (GND), X11.4; also elsewhere on the board
unnamed: R34.1, U9.5 (OUT)
unnamed: Q3.1 (G), R34.2
unnamed: Q3.2 (D), X11.1
unnamed: X11.2, X11.3

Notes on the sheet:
Bourns: 3W 10mOhm CRA2512-FZ-R010ELF

Board: 2 copper layers, 181 parts (0 on the bottom side), 107 nets, no tracks yet.

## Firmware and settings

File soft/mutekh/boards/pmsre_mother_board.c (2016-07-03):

#include <device/device.h>
#include <device/driver.h>
#include <device/shell.h>
#include <device/resources.h>
#include <device/irq.h>
#include <device/class/iomux.h>
#include <device/clock.h>
#include <device/class/cmu.h>
#include <device/class/uart.h>
#include <device/class/spi.h>
#include <device/class/gpio.h>
#include <mutek/console.h>
#include <mutek/printk.h>

#include <arch/stm32/f1/irq.h>
#include <arch/stm32/f1/periph.h>
#include <hexo/iospace.h>

/* CPU */

DEV_DECLARE_STATIC(cpu_dev, "cpu", DEVICE_FLAG_CPU, arm32m_drv,
                   DEV_STATIC_RES_ID(0, 0),
                   DEV_STATIC_RES_FREQ(64000000, 1),
                   );

#include <hexo/endian.h>
#include <hexo/iospace.h>
#include <arch/stm32/f1/rcc.h>
#include <mutek/startup.h>

#include "fpga.h"

#define __IO volatile

struct stm32f1xx_flash_dev_s
{
  __IO uint32_t FLASH_ACR;
  __IO uint32_t FLASH_KEYR;
  __IO uint32_t FLASH_OPTKEYR;
  __IO uint32_t FLASH_SR;
  __IO uint32_t FLASH_CR;
  __IO uint32_t FLASH_AR;
  __IO uint32_t __reserved0;
  __IO uint32_t FLASH_OBR;
  __IO uint32_t FLASH_WRPR;
} __attribute__ ((packed));

#define STM32_FLASH_LAT_WS(n)   ((n) & 0x7)

void stm32_clock_init(void)
{
  uint32_t x;

  __IO struct stm32f1xx_flash_dev_s *flash_dev =
    (struct stm32f1xx_flash_dev_s *) 0x40022000;

  /* disable interrupts. */
  cpu_mem_write_32(STM32_RCC_ADDR + STM32_RCC_CIR_ADDR, 0);

  /* PLL OFF, PLLI2S OFF, HSE ON, HSI OFF. */
  cpu_mem_write_32(STM32_RCC_ADDR + STM32_RCC_CR_ADDR,
    endian_le32(STM32_RCC_CR_HSEON));

  /* wait for hse stability. */
  do
    {
      x = endian_le32(cpu_mem_read_32(STM32_RCC_ADDR + STM32_RCC_CR_ADDR));
    }
  while (!(x & STM32_RCC_CR_HSERDY));

  /* set pll to 64MHz. */
  x = 0;
  STM32_RCC_CFGR_PLLSRC_SET(x, HSE);
  STM32_RCC_CFGR_PLLXTPRE_SET(x, DIV_1);
  STM32_RCC_CFGR_PLLMUL_SET(x, MUL_4);
  cpu_mem_write_32(STM32_RCC_ADDR + STM32_RCC_CFGR_ADDR, endian_le32(x));

  /* switch the pll on. */
  x = endian_le32(cpu_mem_read_32(STM32_RCC_ADDR + STM32_RCC_CR_ADDR));
  STM32_RCC_CR_PLLON_SET(x, 1);
  cpu_mem_write_32(STM32_RCC_ADDR + STM32_RCC_CR_ADDR, endian_le32(x));

  /* wait until pll is locked. */
  do
    {
      x = endian_le32(cpu_mem_read_32(STM32_RCC_ADDR + STM32_RCC_CR_ADDR));
    }
  while (!(x & STM32_RCC_CR_PLLRDY));

  /* set wait cycles for the flash. */
  flash_dev->FLASH_ACR = STM32_FLASH_LAT_WS(2);

  /* configure prescalers. */
  x = endian_le32(cpu_mem_read_32(STM32_RCC_ADDR + STM32_RCC_CFGR_ADDR));
  STM32_RCC_CFGR_HPRE_SET(x, DIV_1);    /* 64MHZ */
  STM32_RCC_CFGR_PPRE1_SET(x, DIV_2);   /* 32MHZ */
  STM32_RCC_CFGR_PPRE2_SET(x, DIV_1);   /* 64MHz */

  /* use the pll @ 72MHz for the system clock. */
  STM32_RCC_CFGR_SW_SET(x, PLL);

  STM32_RCC_CFGR_MCO_SET(x, HSI);
  cpu_mem_write_32(STM32_RCC_ADDR + STM32_RCC_CFGR_ADDR, endian_le32(x));

  /* wait for system clock to be sourced by the pll. */
  do
    {
      x = endian_le32(cpu_mem_read_32(STM32_RCC_ADDR + STM32_RCC_CFGR_ADDR));
    }
  while (!(x & STM32_RCC_CFGR_SWS_PLL));

  /* enable all clock gates. */
  cpu_mem_write_32(STM32_RCC_ADDR + STM32_RCC_AHBENR_ADDR, -1);
  cpu_mem_write_32(STM32_RCC_ADDR + STM32_RCC_APB1ENR_ADDR, -1);
  cpu_mem_write_32(STM32_RCC_ADDR + STM32_RCC_APB2ENR_ADDR, -1);

  /* output mco on a8 */
  cpu_mem_write_32(0x40010800 + 0x04, /* io banks */ 0x4444444b);
}

/* GPIO A..E. */
DEV_DECLARE_STATIC(gpio_dev, "gpio", 0, stm32_gpio_drv,
                   DEV_STATIC_RES_DEV_ICU("/cpu"),
                   DEV_STATIC_RES_IRQ(0, STM32_IRQ_EXTI0,     DEV_IRQ_SENSE_HIGH_LEVEL, 0, 0x1),
                   DEV_STATIC_RES_IRQ(1, STM32_IRQ_EXTI1,     DEV_IRQ_SENSE_HIGH_LEVEL, 0, 0x1),
                   DEV_STATIC_RES_IRQ(2, STM32_IRQ_EXTI2,     DEV_IRQ_SENSE_HIGH_LEVEL, 0, 0x1),
                   DEV_STATIC_RES_IRQ(3, STM32_IRQ_EXTI3,     DEV_IRQ_SENSE_HIGH_LEVEL, 0, 0x1),
                   DEV_STATIC_RES_IRQ(4, STM32_IRQ_EXTI4,     DEV_IRQ_SENSE_HIGH_LEVEL, 0, 0x1),
                   DEV_STATIC_RES_IRQ(5, STM32_IRQ_EXTI9_5,   DEV_IRQ_SENSE_HIGH_LEVEL, 0, 0x1),
                   DEV_STATIC_RES_IRQ(6, STM32_IRQ_EXTI15_10, DEV_IRQ_SENSE_HIGH_LEVEL, 0, 0x1)
);

/* USART 2 */
DEV_DECLARE_STATIC(usart2_dev, "uart2", 0, stm32_usart_drv,
    DEV_STATIC_RES_MEM(STM32_USART2_ADDR, STM32_USART2_ADDR + STM32_USART2_SIZE),

    DEV_STATIC_RES_FREQ(32000000, 1),

    DEV_STATIC_RES_DEV_ICU("/cpu"),
    DEV_STATIC_RES_IRQ(0, STM32_IRQ_USART2, DEV_IRQ_SENSE_HIGH_LEVEL, 0, 0x1),

    DEV_STATIC_RES_DEV_PARAM("iomux", "/gpio"),
    DEV_STATIC_RES_IOMUX("tx", 0, /* PA2 */ 0*16+2, 0, 0),
    DEV_STATIC_RES_IOMUX("rx", 0, /* PA3 */ 0*16+3, 0, 0),

    DEV_STATIC_RES_UART(9600, 8, DEV_UART_PARITY_NONE, 1, 0, 0)
);

/* FPGA programming */
DEV_DECLARE_STATIC(spi1_dev, "spi1", 0, stm32_spi_drv,
                   DEV_STATIC_RES_MEM(STM32_SPI1_ADDR, STM32_SPI1_ADDR + STM32_SPI1_SIZE),

                   DEV_STATIC_RES_FREQ(64000000, 1),

                   DEV_STATIC_RES_DEV_ICU("/cpu"),
                   DEV_STATIC_RES_IRQ(0, STM32_IRQ_SPI1, DEV_IRQ_SENSE_RISING_EDGE, 0, 0x1),

                   DEV_STATIC_RES_DEV_IOMUX("/gpio"),
                   DEV_STATIC_RES_IOMUX("clk", 0, 0*16+5 /* PA5 */, 0 /* no remap */, 0),
                   DEV_STATIC_RES_IOMUX("miso", 0, 0*16+6 /* PA6 */, 0 /* no remap */, 0),
                   DEV_STATIC_RES_IOMUX("mosi", 0, 0*16+7 /* PA7 */, 0 /* no remap */, 0)
                   );

/* DAC/FPGA */
DEV_DECLARE_STATIC(spi2_dev, "spi2", 0, stm32_spi_drv,
                   DEV_STATIC_RES_MEM(STM32_SPI2_ADDR, STM32_SPI2_ADDR + STM32_SPI2_SIZE),

                   DEV_STATIC_RES_FREQ(64000000, 1),

                   DEV_STATIC_RES_DEV_ICU("/cpu"),
                   DEV_STATIC_RES_IRQ(0, STM32_IRQ_SPI2, DEV_IRQ_SENSE_RISING_EDGE, 0, 0x1),

                   DEV_STATIC_RES_DEV_IOMUX("/gpio"),
                   DEV_STATIC_RES_IOMUX("clk", 0, 1*16+13 /* PB13 */, 0 /* no remap */, 0),
                   DEV_STATIC_RES_IOMUX("miso", 0, 1*16+14 /* PB14 */, 0 /* no remap */, 0),
                   DEV_STATIC_RES_IOMUX("mosi", 0, 1*16+15 /* PB15 */, 0 /* no remap */, 0)
                   );

DEV_DECLARE_STATIC(timer4_dev, "timer4", 0, stm32_timer_drv,
                   DEV_STATIC_RES_MEM(STM32_TIM4_ADDR, STM32_TIM4_ADDR + STM32_TIM4_SIZE),
                   DEV_STATIC_RES_FREQ(64000000, 1),

                   DEV_STATIC_RES_DEV_ICU("/cpu"),
                   DEV_STATIC_RES_IRQ(0, STM32_IRQ_TIM4, DEV_IRQ_SENSE_HIGH_LEVEL, 0, 0x1),
                   );

#define COM_CS_IO        35
#define DAC_CS_IO        28
#define FPGA_DONE_IO     1
#define FPGA_INITB_IO    4
#define FPGA_PROGB_IO    25

struct device_spi_ctrl_s d_cmd_spi;
struct device_spi_ctrl_s d_fpga_spi;
struct device_gpio_s d_gpio;

static void pmsre_spi_write(struct device_spi_ctrl_s *spi, unsigned int cs_id,
                            const uint8_t *data, size_t size)
{
  struct dev_spi_ctrl_transfer_s tr = {
    .data.count = size,
    .data.out = data,
    .data.out_width = 1,
  };

  ensure(!dev_gpio_out(&d_gpio, cs_id, 0));
  ensure(!dev_spi_wait_transfer(&d_cmd_spi, &tr));
  ensure(!dev_gpio_out(&d_gpio, cs_id, 1));
}

void main()
{
  ensure(!device_get_accessor_by_path(&d_fpga_spi.base, NULL, "spi1", DRIVER_CLASS_SPI_CTRL));
  ensure(!device_get_accessor_by_path(&d_cmd_spi.base, NULL, "spi2", DRIVER_CLASS_SPI_CTRL));
  ensure(!device_get_accessor_by_path(&d_gpio.base, NULL, "gpio", DRIVER_CLASS_GPIO));

  ensure(!dev_gpio_mode(&d_gpio, FPGA_DONE_IO, DEV_PIN_INPUT_PULLUP));
  ensure(!dev_gpio_mode(&d_gpio, FPGA_INITB_IO, DEV_PIN_INPUT_PULLUP));

  ensure(!dev_gpio_mode(&d_gpio, FPGA_PROGB_IO, DEV_PIN_PUSHPULL));
  ensure(!dev_gpio_out(&d_gpio, FPGA_PROGB_IO, 0));

  /* drive CS */
  ensure(!dev_gpio_mode(&d_gpio, DAC_CS_IO, DEV_PIN_PUSHPULL));
  ensure(!dev_gpio_out(&d_gpio, DAC_CS_IO, 1));

  ensure(!dev_gpio_mode(&d_gpio, COM_CS_IO, DEV_PIN_PUSHPULL));
  ensure(!dev_gpio_out(&d_gpio, COM_CS_IO, 1));

  struct dev_spi_ctrl_config_s cfg = {
    .ck_mode = DEV_SPI_CK_MODE_0,
    .bit_order = DEV_SPI_MSB_FIRST,
    .miso_pol = cfg.mosi_pol = DEV_SPI_ACTIVE_HIGH,
    .bit_rate = 1000000,
    .word_width = 8,
  };

  ensure(!DEVICE_OP(&d_cmd_spi, config, &cfg));
  ensure(!DEVICE_OP(&d_fpga_spi, config, &cfg));

  /* set dac reference to internal 2.0v */
  pmsre_spi_write(&d_cmd_spi, DAC_CS_IO, (const uint8_t*)"\x76\x0f\x00", 3);

  printk("PMSRE init done\n");
}

enum shell_pmsre_opts_e
{
  PMSRE_OPT_AXIS = 1,
  PMSRE_OPT_MAMPS = 2,
};

struct termui_optctx_pmsre_opts
{
  uint8_t  axis;
  uint16_t mamps;
};

static TERMUI_CON_COMMAND_PROTOTYPE(shell_pmsre_fpga_load)
{
  /* pulse prog_b low */
  ensure(!dev_gpio_out(&d_gpio, FPGA_PROGB_IO, 0));
  ensure(!dev_gpio_out(&d_gpio, FPGA_PROGB_IO, 1));

  while (!dev_gpio_input(&d_gpio, FPGA_INITB_IO, NULL))
    ;

  printk("INITB ok, writing %u bytes\n", fpga_stream_size);

  struct dev_spi_ctrl_transfer_s tr = {
    .data.count = fpga_stream_size,
    .data.out = fpga_stream,
    .data.out_width = 1,
  };

  ensure(!dev_spi_wait_transfer(&d_fpga_spi, &tr));

  printk("DONE: %u\n", dev_gpio_input(&d_gpio, FPGA_DONE_IO, NULL));

  return 0;
}

static TERMUI_CON_COMMAND_PROTOTYPE(shell_pmsre_motor)
{
  struct termui_optctx_pmsre_opts *c = ctx;

  if (used & PMSRE_OPT_MAMPS)
    {
      uint8_t id = c->axis > 2 ? 3 : 2 - c->axis;
      /*
         drv8825 vref = amps / 2
         max5713 val = vout * 2048
      */
      uint16_t val = c->mamps * 2048 / 1000 / 2;
      uint8_t dac_cmd[3] = { 0x30 | id, val >> 4, val << 4 };
      pmsre_spi_write(&d_cmd_spi, DAC_CS_IO, dac_cmd, 3);
    }

  return 0;
}

static TERMUI_CON_OPT_DECL(pmsre_opts) =
{
  TERMUI_CON_OPT_INTEGER_RANGE_ENTRY("-x", "--axis", PMSRE_OPT_AXIS, struct termui_optctx_pmsre_opts, axis, 1, 0, 5,
                               TERMUI_CON_OPT_CONSTRAINTS(0, 0)
                               )

  TERMUI_CON_OPT_INTEGER_RANGE_ENTRY("-a", "--mA", PMSRE_OPT_MAMPS, struct termui_optctx_pmsre_opts, mamps, 1, 0, 2500,
                               TERMUI_CON_OPT_CONSTRAINTS(0, 0))

  TERMUI_CON_LIST_END
};

static TERMUI_CON_GROUP_DECL(shell_pmsre_subgroup) =
{
  TERMUI_CON_ENTRY(shell_pmsre_motor, "motor",
                   TERMUI_CON_OPTS_CTX(pmsre_opts, PMSRE_OPT_AXIS, PMSRE_OPT_MAMPS, NULL)
                   )

  TERMUI_CON_ENTRY(shell_pmsre_fpga_load, "fpga_load",
                   )

  TERMUI_CON_LIST_END
};

MUTEK_SHELL_ROOT_GROUP(shell_pmsre_subgroup, "pmsre")

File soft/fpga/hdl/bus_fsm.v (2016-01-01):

/* -*- tab-width: 4 -*- */
module bus_fsm(
	       input 		clk,
	       input [7:0] 	spi_in,
	       input 		spi_cs,
	       input 		spi_valid,
	       input [31:0] 	ram_in,
	       output [31:0] 	ram_out,
	       output [6:0] 	ram_addr,
	       output reg 	ram_read,
	       output reg 	ram_write,
	       output reg [7:0] spi_out
	       );

   /* FSM states */
   localparam IDLE  = 4'b1000;
   localparam RAM_R = 4'b1001;
   localparam RAM_W = 4'b1010;
   localparam R0 = 4'b0000;
   localparam R1 = 4'b0001;
   localparam R2 = 4'b0010;
   localparam R3 = 4'b0011;
   localparam W0 = 4'b0100;
   localparam W1 = 4'b0101;
   localparam W2 = 4'b0110;
   localparam W3 = 4'b0111;

   reg [3:0] 			 state = IDLE;
   reg 				 valid_d = 0;

   reg [6:0] 			 addr = 0;
   reg [31:0] 			 out = 0;
   reg [31:0] 			 in;

   wire 			 valid_strobe;
   assign valid_strobe = (!valid_d & spi_valid);

   always @(posedge clk)
     begin
	 valid_d <= spi_valid;
	 if(spi_cs) begin
	     state <= IDLE;
	 end else begin
	     case(state)
	       IDLE: 
		 if(valid_strobe) begin
		     state <= (spi_in[7]) ? W0 : RAM_R;
		     addr <= spi_in[6:0];
		 end
	       RAM_R: begin
		   state <= R0;
		   in <= ram_in;
		 end
	       R0:
		 if(valid_strobe) begin
		     state <= R1;
		 end
	       R1:
		 if(valid_strobe) begin
		     state <= R2;
		 end
	       R2:
		 if(valid_strobe) begin
		     state <= R3;
		 end
	       R3:
		 if(valid_strobe) begin
		     state <= IDLE;
		 end
	       W0:
		 if(valid_strobe) begin
		     state <= W1;
		     out[31:24] <= spi_in;
		 end
	       W1:
		 if(valid_strobe) begin
		     state <= W2;
		     out[23:16] <= spi_in;
		 end
	       W2:
		 if(valid_strobe) begin
		     state <= W3;
		     out[15:8] <= spi_in;
		 end
	       W3:
		 if(valid_strobe) begin
		     state <= RAM_W;
		     out[7:0] <= spi_in;
		 end
	       RAM_W:
		 begin
		     state <= IDLE;
		 end
	     endcase
	 end
     end

   assign ram_out = out;
   assign ram_addr = addr;

   always @*
     begin
	 ram_read = 0;
	 ram_write = 0;
	 spi_out = 0;
	 case(state)
	   IDLE: begin
	   end
	   RAM_R: begin
	       ram_read = 1;
	   end
	   R0: begin
	       spi_out = in[31:24];
	   end
	   R1: begin
	       spi_out = in[23:16];
	   end
	   R2: begin
	       spi_out = in[15:8];
	   end
	   R3: begin
	       spi_out = in[7:0];
	   end
	   RAM_W: begin
	       ram_write = 1;
	   end
	 endcase
     end

endmodule

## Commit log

2014-11-20 start xc3s200a schematic
2014-12-05 continue spartan 3 schematic
2014-12-05 done spartan 3a schematic
    [psu.sch, stepper_controller.kicad_pcb, stepper_controller.sch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]
2014-12-06 added fpga configuration
    [fpga.sch, psu.sch, stepper_controller.kicad_pcb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]
2014-12-07 added 1.2V schematic
    [fpga.sch, psu.sch, stepper_controller.kicad_pcb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]
2015-01-04 added dac start routing
    [fpga.sch, psu.sch, stepper_controller.kicad_pcb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]
2015-01-04 placing USB and motor connector
    [stepper_controller.kicad_pcb]
2015-01-06 Changed motor connector => 4 layers board
    [fpga.sch, psu.sch, stepper_controller.kicad_pcb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]
2015-01-10 boring commit message
    [fpga.sch, psu.sch, stepper_controller.kicad_pcb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]
2015-01-11 routing first driver
    [fpga.sch, psu.sch, stepper_controller.kicad_pcb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]
2015-01-12 routed 3 drivers
    [psu.sch, stepper_controller.kicad_pcb, stepper_controller.sch]
2015-01-12 RER B blablabla
    [fpga.sch, psu.sch, stepper_controller.kicad_pcb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]
2015-01-13 routed 12->3.3v miss mezzanine header
    [fpga.sch, psu.sch, stepper_controller.kicad_pcb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]
2015-01-13 added lib resistors
2015-01-14 blabla vroum vroum
    [fpga.sch, psu.sch, stepper_controller.kicad_pcb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]
2015-01-18 added decoupling capacitor + 4 pin connector
    [fpga.sch, psu.sch, stepper_controller.kicad_pcb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]
2015-01-18 routing crap
    [stepper_controller.kicad_pcb]
2015-01-20 added fixing hole - capacitor on vref
    [fpga.sch, psu.sch, stepper_controller.kicad_pcb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]
2015-01-21 footprint cleanup
    [fpga.sch, psu.sch, stepper_controller.kicad_pcb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]
2015-01-22 Footprint assign cleanup done
    [fpga.sch, psu.sch, stepper_controller.sch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]
2015-01-25 adding mezzanine connector
    [fpga.sch, psu.sch, stepper_controller.kicad_pcb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]
2015-01-26 jtag con & serial
    [fpga.sch, psu.sch, stepper_controller.kicad_pcb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]
2015-01-27 routing adc connector + SPI | removed mode selector
    [fpga.sch, psu.sch, stepper_controller.kicad_pcb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]
2015-01-29 routing adc input
    [fpga.sch, psu.sch, stepper_controller.kicad_pcb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]
2015-01-30 added an other 7 point connector
    [fpga.sch, psu.sch, stepper_controller.kicad_pcb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]
2015-01-31 last commit before gerber checking
    [fpga.sch, psu.sch, stepper_controller.kicad_pcb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]
2015-02-01 Finished silkscreen time to sleep
    [stepper_controller-BOTTOM.gbl, stepper_controller-B_Mask.gbs, stepper_controller-B_Paste.gbp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]
2015-02-01 added fpga/arm/driver doc
2015-02-01 added output D for dac
    [fpga.sch, psu.sch, stepper_controller.kicad_pcb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]
2015-02-01 first gerber release
    [fpga.sch, psu.sch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]
2015-02-02 cleaned part: now use kicad-component repository
    [fpga.sch, psu.sch, stepper_controller.sch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]
2015-03-03 converted PCB to Kicad 2014
    [stepper_controller.kicad_pcb]
2015-03-12 changing capacitor and correcting some net
    [fpga.sch, psu.sch, stepper_controller.kicad_pcb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]
2015-03-12 removed old component traces + migrated pcbnew file
    [stepper_controller.csv, stepper_controller.kicad_pcb, stepper_controller.sch]
2015-03-16 starting BOM
    [fpga.sch, psu.sch, stepper_controller.csv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]
2015-03-29 correction + BOM
    [fpga.sch, psu.sch, stepper_controller.csv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]
2015-06-04 hard: working board by nats
    [fpga.sch, psu.sch, stepper_controller.csv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]
2015-06-06 soft: add basic software files
    [pmsre.cfg]
2015-11-23 mutekh: working spi
2015-11-28 shell: motor current and fpga loading
2015-12-06 Working RAM + SPI: Tested S3AN StarterKit
2015-12-13 1st working fpga code, ok for 3 motors
2015-12-13 added pullups on motor fault
2016-01-23 new spi register set
2016-04-13 added irq and cs line
    [fpga.sch, psu.sch, stepper_controller.kicad_pcb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]
2016-11-26 starting ICE based board
    [icemotv1.brd, icemotv1.sch]
2016-11-27 adding decoupling and usb connector
    [icemotv1.brd, icemotv1.sch]
2016-11-27 added xtal, usb to be checked
    [icemotv1.brd, icemotv1.sch]
2016-11-27 starting ICE schematic
    [icemotv1.brd, icemotv1.sch]
2016-11-27 need to add interface to motor
    [icemotv1.brd, icemotv1.sch]
2016-11-27 added oscillator, clock to be routed on GBin
    [icemotv1.brd, icemotv1.sch]
2016-11-27 added res on decay
    [icemotv1.brd, icemotv1.sch]
2016-12-17 remove ICE40 and EFM32, add a S6 LX9
    [icemotv1.brd, icemotv1.sch]
2016-12-19 added ADC DCDC and copied 5 drv8825
    [icemotv1.brd, icemotv1.sch]
2017-03-08 added a 12V rail, Power Mosfet
    [icemotv1.brd, icemotv1.sch]
2017-04-02 added ADC and opamp for mosfet
    [icemotv1.brd, icemotv1.sch]
